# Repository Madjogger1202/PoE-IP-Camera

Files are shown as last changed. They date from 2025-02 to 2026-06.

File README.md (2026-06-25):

# PoE-IP-Camera

**IP-камера на ESP32-CAM с питанием от PoE (с гальванической развязкой), USB или DC-Jack и STM32-буфером между Ethernet и камерой.**

Плата сетевой камеры, где полезной нагрузкой выступает модуль **ESP32-CAM**, а связку с проводной сетью обеспечивает **Ethernet-контроллер**, подключённый к **STM32**, работающей буфером/мостом. Питание выбирается из трёх источников: **PoE**, **USB** или **DC-Jack (4.2–13 В)**. PoE-вход выполнен с гальванической развязкой. На ESP32-CAM реализуются веб-функции: Telegram-бот и API.

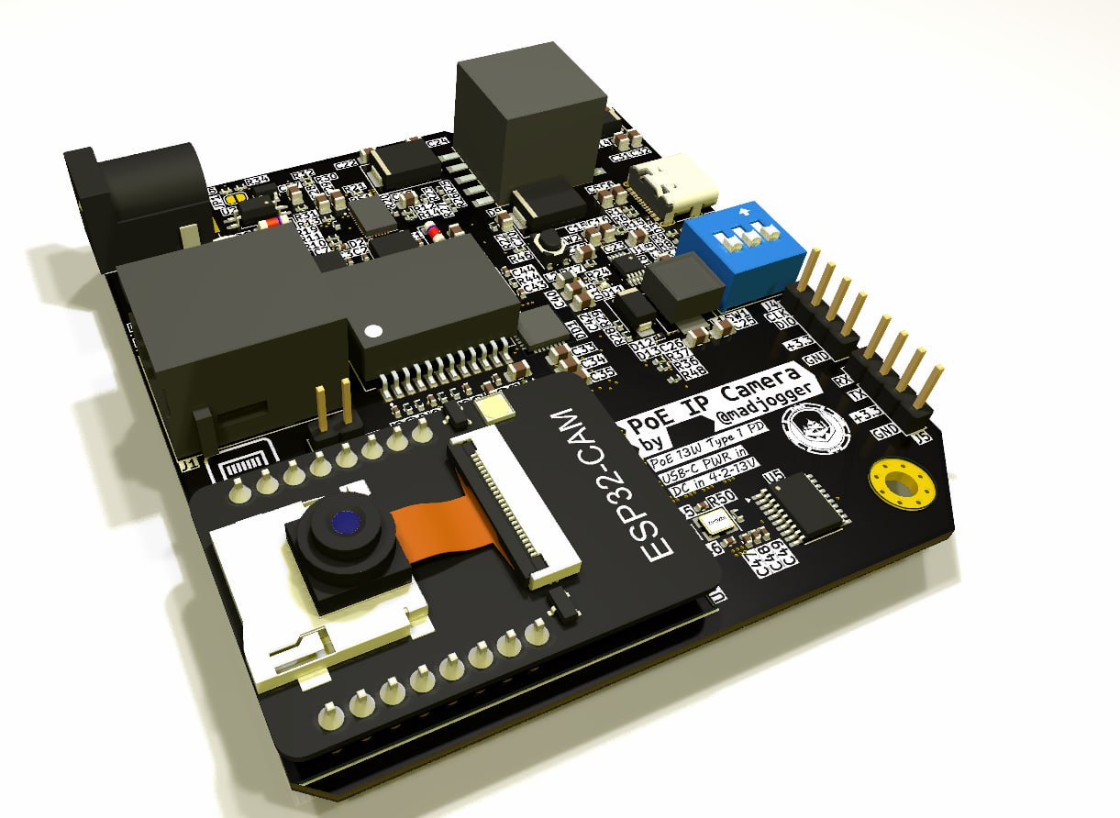
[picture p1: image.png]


## Обзор

- **Название проекта:** PoE-IP-Camera
- **Камера/нагрузка:** модуль ESP32-CAM (веб-сервер, Telegram-бот, API)
- **Сетевой узел:** Ethernet-контроллер + STM32 в роли буфера
- **Питание:** PoE (с развязкой) / USB / DC-Jack 4.2–13 В
- **Особенность:** изолированный PoE-вход — первый опыт проектирования гальванической развязки

## Ключевые особенности

- **Три источника питания** — PoE, USB или DC-Jack (4.2–13 В) на выбор
- **PoE с гальванической развязкой** — изолированный преобразователь питания на стороне PoE
- **ESP32-CAM как полезная нагрузка** — камера + Wi-Fi/обработка, веб-функции (Telegram-бот, API)
- **STM32-буфер** — промежуточное звено между Ethernet-контроллером и ESP32-CAM
- **Проводная сеть** — Ethernet-интерфейс для стабильного подключения и питания по одному кабелю (PoE)

## Архитектура

```
Сеть (Ethernet/PoE) ──► Ethernet-контроллер ──► STM32 (буфер) ──► ESP32-CAM (камера + веб)
                                                                       │
PoE / USB / DC-Jack ──► узел питания (PoE с развязкой) ────────────────┘
```

Сигнал из сети поступает на Ethernet-контроллер, который связан с STM32. STM32 работает буфером/мостом и передаёт данные на модуль ESP32-CAM — основную полезную нагрузку, на которой реализуются веб-интерфейс, Telegram-бот и API. Питание камера может получать по тому же кабелю (PoE) либо от USB/DC-Jack.

## Питание

Реализован выбор из трёх источников:

- **PoE** — питание по сетевому кабелю с **гальванической развязкой** (изолированный преобразователь)
- **USB** — питание от USB-разъёма
- **DC-Jack** — внешний вход **4.2–13 В**

Развязанный PoE-узел проектировался впервые и занял заметную часть работы; результат подтвердил корректность подхода.

## Что на плате

| Блок | Назначение |
|---|---|
| ESP32-CAM | Камера и веб-нагрузка (Telegram-бот, API) |
| Ethernet-контроллер | Проводной сетевой интерфейс |
| STM32 | Буфер/мост между Ethernet и ESP32-CAM |
| Узел питания PoE | Изолированный преобразователь (гальваническая развязка) |
| Выбор питания | Коммутация PoE / USB / DC-Jack (4.2–13 В) |

## Применение

- Сетевая IP-камера с питанием по одному кабелю (PoE)
- Удалённое наблюдение с управлением через Telegram-бот / API
- Узел видеомониторинга для систем с проводной сетью
- Платформа для экспериментов с PoE и связкой Ethernet ↔ ESP32-CAM

## Среда разработки

- **Схема и плата:** KiCad
- **Прошивка ESP32-CAM:** PlatformIO / Arduino (веб-сервер, Telegram-бот, API)
- **Прошивка STM32:** STM32Cube / PlatformIO

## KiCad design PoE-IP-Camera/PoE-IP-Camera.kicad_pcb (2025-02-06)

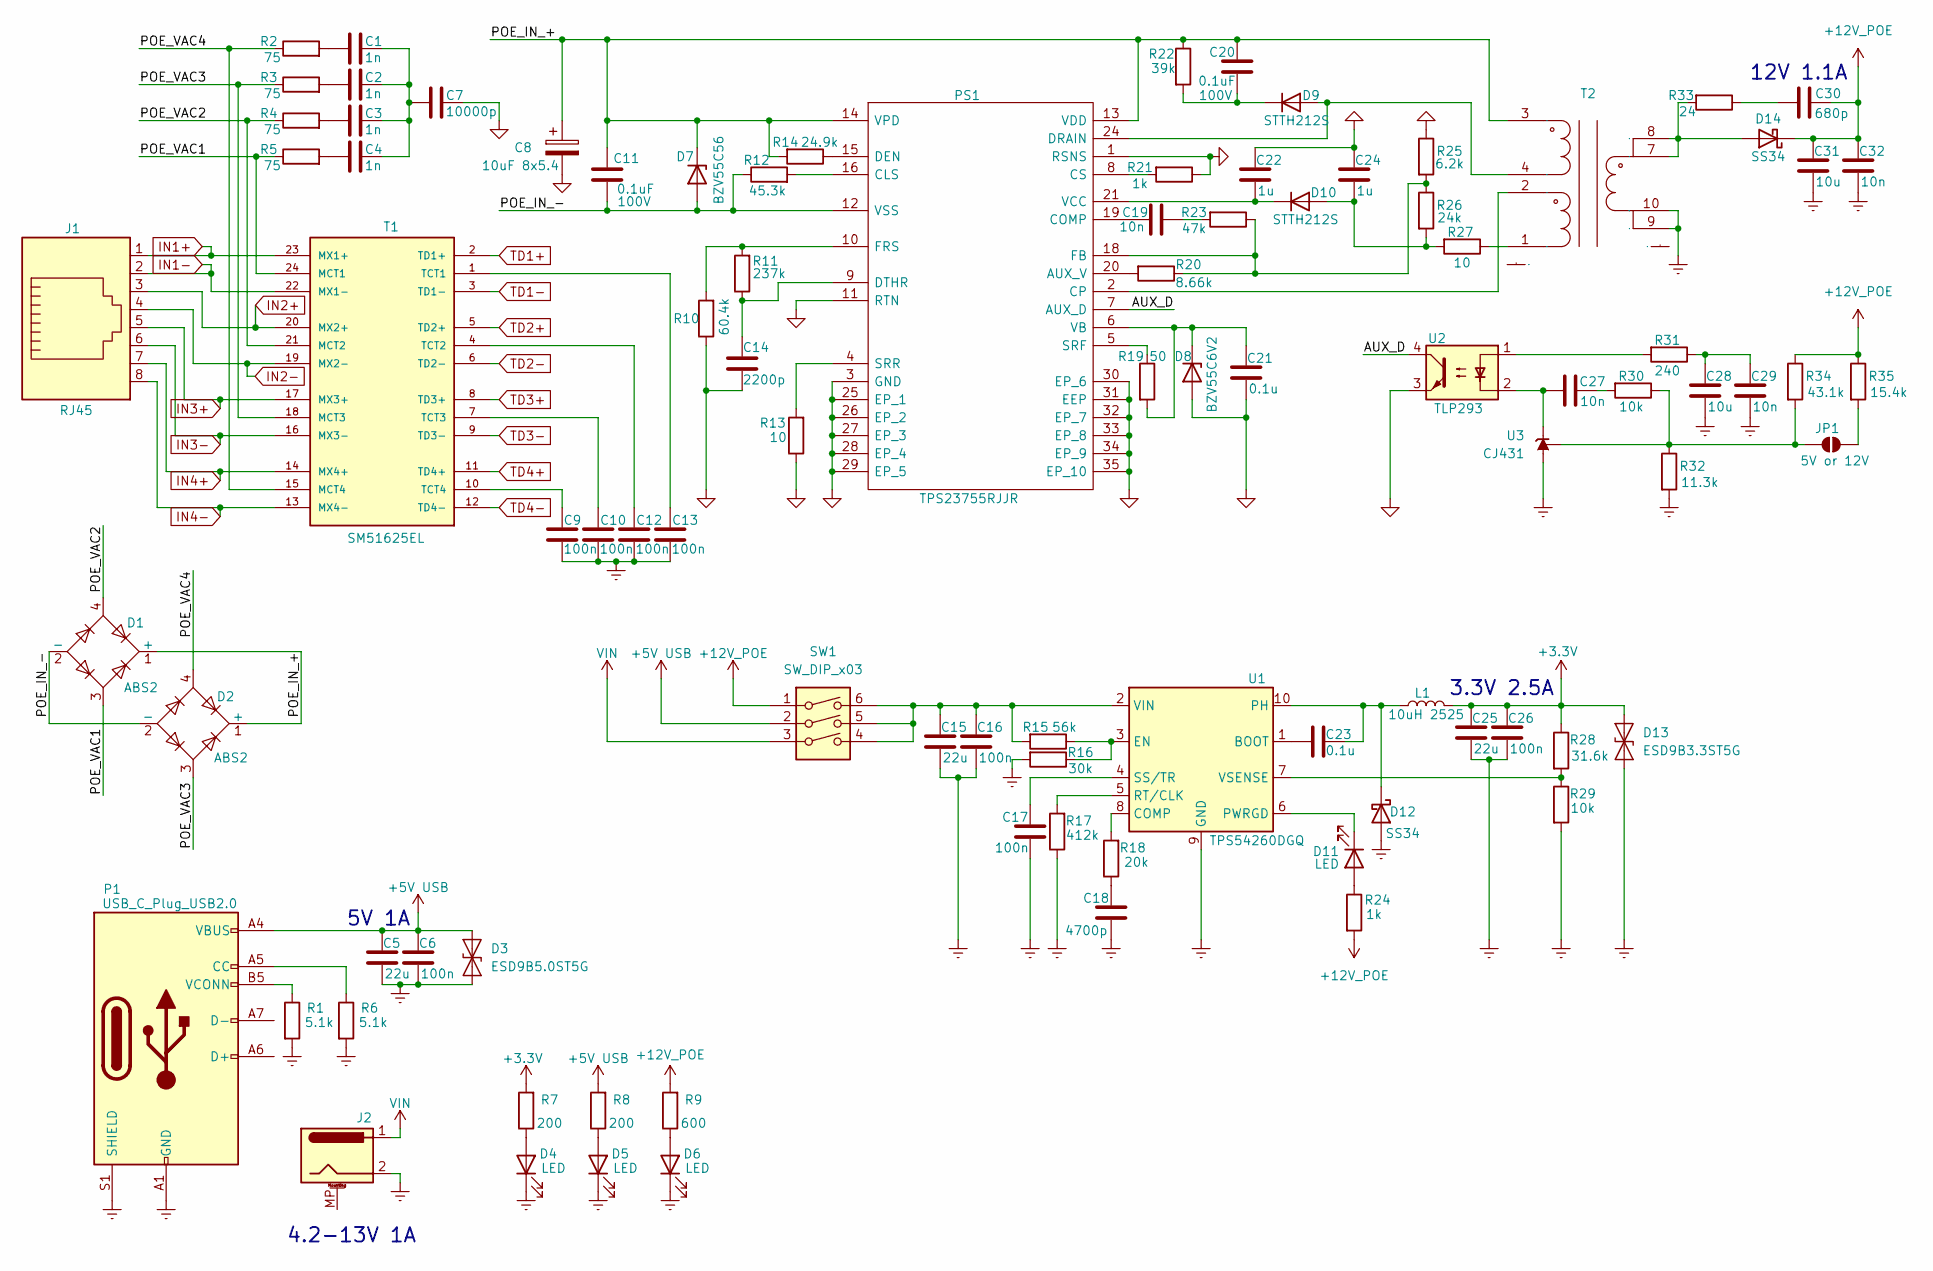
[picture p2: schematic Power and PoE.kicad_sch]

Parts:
C1, C2, C3, C4: 1n; C_0402_1005Metric
C5, C15, C25: 22u; C_0805_2012Metric
C6, C16, C17, C26: 100n; C_0805_2012Metric
C7: 10000p; C_0402_1005Metric
C8: 10uF 8x5.4; CP_Elec_8x5.4
C9, C10, C12, C13: 100n; C_0402_1005Metric
C11, C20: 0.1uF; C_0805_2012Metric
C14: 2200p; C_0805_2012Metric
C18: 4700p; C_0805_2012Metric
C19, C27, C29, C32: 10n; C_0805_2012Metric
C21, C23: 0.1u; C_0805_2012Metric
C22, C24: 1u; C_0805_2012Metric
C28, C31: 10u; C_0805_2012Metric
C30: 680p; C_0805_2012Metric
D1, D2: ABS2; Diode_Bridge_Diotec_ABS
D3: ESD9B5.0ST5G; D_SOD-923
D4, D5, D6, D11: LED; LED_0402_1005Metric
D7: BZV55C56; D_MiniMELF
D8: BZV55C6V2; D_MiniMELF
D9, D10: STTH212S; D_SMC
D12, D14: SS34; D_SMA
D13: ESD9B3.3ST5G; D_SOD-923
J1: RJ45; RJ45_Amphenol_54602-x08_Horizontal
J2: Barrel_Jack_MountingPin; BarrelJack_GCT_DCJ200-10-A_Horizontal
JP1: SolderJumper_2_Open; SolderJumper-2_P1.3mm_Open_RoundedPad1.0x1.5mm
L1: 10uH 2525; L_Vishay_IHLP-2525
P1: USB_C_Plug_USB2.0; USB_C_Receptacle_G-Switch_GT-USB-7010ASV
PS1: TPS23755RJJR
R1, R6: 5.1k; R_0402_1005Metric
R2, R3, R4, R5: 75; R_0402_1005Metric
R7, R8: 200; R_0402_1005Metric
R9: 600; R_0402_1005Metric
R10: 60.4k; R_0402_1005Metric
R11: 237k; R_0402_1005Metric
R12: 45.3k; R_0402_1005Metric
R13, R27: 10; R_0402_1005Metric
R14: 24.9k; R_0402_1005Metric
R15: 56k; R_0402_1005Metric
R16: 30k; R_0402_1005Metric
R17: 412k; R_0402_1005Metric
R18: 20k; R_0402_1005Metric
R19: 50; R_0402_1005Metric
R20: 8.66k; R_0402_1005Metric
R21, R24: 1k; R_0402_1005Metric
R22: 39k; R_0402_1005Metric
R23: 47k; R_0402_1005Metric
R25: 6.2k; R_0402_1005Metric
R26: 24k; R_0402_1005Metric
R28: 31.6k; R_0402_1005Metric
R29, R30: 10k; R_0402_1005Metric
R31: 240; R_0402_1005Metric
R32: 11.3k; R_0402_1005Metric
R33: 24; R_1206_3216Metric
R34: 43.1k; R_0402_1005Metric
R35: 15.4k; R_0402_1005Metric
SW1: SW_DIP_x03; SW_DIP_SPSTx03_Slide_9.78x9.8mm_W7.62mm_P2.54mm
T1: SM51625EL; XFMR_SM51625EL
T2: XFMR-SMD_HR051142; Manufacturer Part HR051142
U1: TPS54260DGQ; MSOP-10-1EP_3x3mm_P0.5mm_EP2.2x3.1mm_Mask1.83x1.89mm_Therma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
U2: TLP293; SOIC-4_4.55x2.6mm_P1.27mm
U3: CJ431; SOT-23

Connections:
+3.3V: C25.1, C26.1, D13.2 (A2), L1.2, R7.2, R28.1; also elsewhere on the board
+5V USB: C5.1, C6.1, D3.2 (A2), P1.A4 (VBUS), P1.A9 (VBUS), P1.B4 (VBUS), P1.B9 (VBUS), R8.2, SW1.2
+12V_POE: C30.2, C31.1, C32.1, D14.1 (K), R9.2, R24.2, R34.1, R35.1, SW1.1
/Power and PoE/AUX_D: PS1.7 (AUX_D), U2.4
/Power and PoE/POE_IN_+: C8.1, C11.1, C20.1, D1.1 (+), D2.1 (+), D7.1 (K), PS1.13 (VDD), PS1.14 (VPD), R14.2, R22.1, T2.3
/Power and PoE/POE_IN_-: C11.2, D1.2 (-), D2.2 (-), D7.2 (A), PS1.12 (VSS), R12.1
/Power and PoE/POE_VAC1: D1.3, R5.1, T1.24 (MCT1)
/Power and PoE/POE_VAC2: D1.4, R4.1, T1.21 (MCT2)
/Power and PoE/POE_VAC3: D2.3, R3.1, T1.18 (MCT3)
/Power and PoE/POE_VAC4: D2.4, R2.1, T1.15 (MCT4)
Earth: C5.2, C6.2, C9.1, C10.1, C12.1, C13.1, C15.2, C16.2, C17.2, C18.2, C25.2, C26.2, C28.2, C29.2, C31.2, C32.2, D3.1 (A1), D4.1 (K), D5.1 (K), D6.1 (K), D12.2 (A), D13.1 (A1), J2.2, P1.A1 (GND), P1.A12 (GND), P1.B1 (GND), P1.B12 (GND), P1.S1 (SHIELD), R1.2, R6.2, R16.2, R17.1, R29.2, R32.2, T2.9, T2.10, U1.9 (GND), U1.11, U3.3 (A); also elsewhere on the board
GND1: C7.1, C8.2, C14.2, C21.2, C22.1, C24.1, D8.2 (A), PS1.1 (RSNS), PS1.3 (GND), PS1.11 (RTN), PS1.25 (EP_1), PS1.26 (EP_2), PS1.27 (EP_3), PS1.28 (EP_4), PS1.29 (EP_5), PS1.30 (EP_6), PS1.31 (EEP), PS1.32 (EP_7), PS1.33 (EP_8), PS1.34 (EP_9), PS1.35 (EP_10), R10.1, R13.1, R21.1, R25.1, U2.3
IN1+: J1.1, T1.23 (MX1+)
IN1-: J1.2, T1.22 (MX1-)
IN2+: J1.3, T1.20 (MX2+)
IN2-: J1.4, T1.19 (MX2-)
IN3+: J1.5, T1.17 (MX3+)
IN3-: J1.6, T1.16 (MX3-)
IN4+: J1.7, T1.14 (MX4+)
IN4-: J1.8, T1.13 (MX4-)
unnamed: C1.1, C2.1, C3.1, C4.1, C7.2
unnamed: C1.2, R2.2
unnamed: C2.2, R3.2
unnamed: C3.2, R4.2
unnamed: C4.2, R5.2
unnamed: C18.1, R18.1
unnamed: C19.2, R23.2
unnamed: C27.2, R30.2
unnamed: C28.1, C29.1, R31.1
unnamed: C30.1, R33.1
unnamed: D4.2 (A), R7.1
unnamed: D5.2 (A), R8.1
unnamed: D6.2 (A), R9.1
unnamed: C21.1, D8.1 (K), PS1.6 (VB), R19.2
unnamed: D9.2 (A), PS1.24 (DRAIN), T2.4
unnamed: C20.2, D9.1 (K), R22.2
unnamed: C24.2, D10.2 (A), R26.2, R27.2
unnamed: C22.2, D10.1 (K), PS1.21 (VCC)
unnamed: D11.2 (A), R24.1
unnamed: D11.1 (K), U1.6 (PWRGD)
unnamed: C23.2, D12.1 (K), L1.1, U1.10 (PH)
unnamed: D14.2 (A), R33.2, T2.7, T2.8
unnamed: JP1.1 (A), R30.1, R32.1, R34.2, U3.1 (REF)
unnamed: JP1.2 (B), R35.2
unnamed: P1.A5 (CC), R6.1
unnamed: P1.B5 (VCONN), R1.1
unnamed: PS1.20 (AUX_V), R20.2
unnamed: PS1.16 (CLS), R12.2
unnamed: C19.1, PS1.19 (COMP)
unnamed: PS1.2 (CP), T2.2
unnamed: PS1.8 (CS), R21.2
unnamed: PS1.15 (DEN), R14.1
unnamed: C14.1, PS1.9 (DTHR), R11.1
unnamed: PS1.18 (FB), R20.1, R23.1, R25.2, R26.1
unnamed: PS1.10 (FRS), R10.2, R11.2
unnamed: PS1.5 (SRF), R19.1
unnamed: PS1.4 (SRR), R13.2
unnamed: R27.1, T2.1
unnamed: R31.2, U2.1
unnamed: C13.2, T1.1 (TCT1)
unnamed: C12.2, T1.4 (TCT2)
unnamed: C10.2, T1.7 (TCT3)
unnamed: C9.2, T1.10 (TCT4)
unnamed: C23.1, U1.1 (BOOT)
unnamed: R18.2, U1.8 (COMP)
unnamed: R15.1, R16.1, U1.3 (EN)
unnamed: R17.2, U1.5 (RT/CLK)
unnamed: C17.1, U1.4 (SS/TR)
unnamed: C15.1, C16.1, R15.2, SW1.4, SW1.5, SW1.6, U1.2 (VIN)
unnamed: R28.2, R29.1, U1.7 (VSENSE)
unnamed: C27.1, U2.2, U3.2 (K)
TD1+: T1.2 (TD1+); also elsewhere on the board
TD1-: T1.3 (TD1-); also elsewhere on the board
TD2+: T1.5 (TD2+); also elsewhere on the board
TD2-: T1.6 (TD2-); also elsewhere on the board
TD3+: T1.8 (TD3+)
TD3-: T1.9 (TD3-)
TD4+: T1.11 (TD4+)
TD4-: T1.12 (TD4-)
VIN: J2.1, SW1.3

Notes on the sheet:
3.3V 2.5A
12V 1.1A
5V 1A
4.2-13V 1A

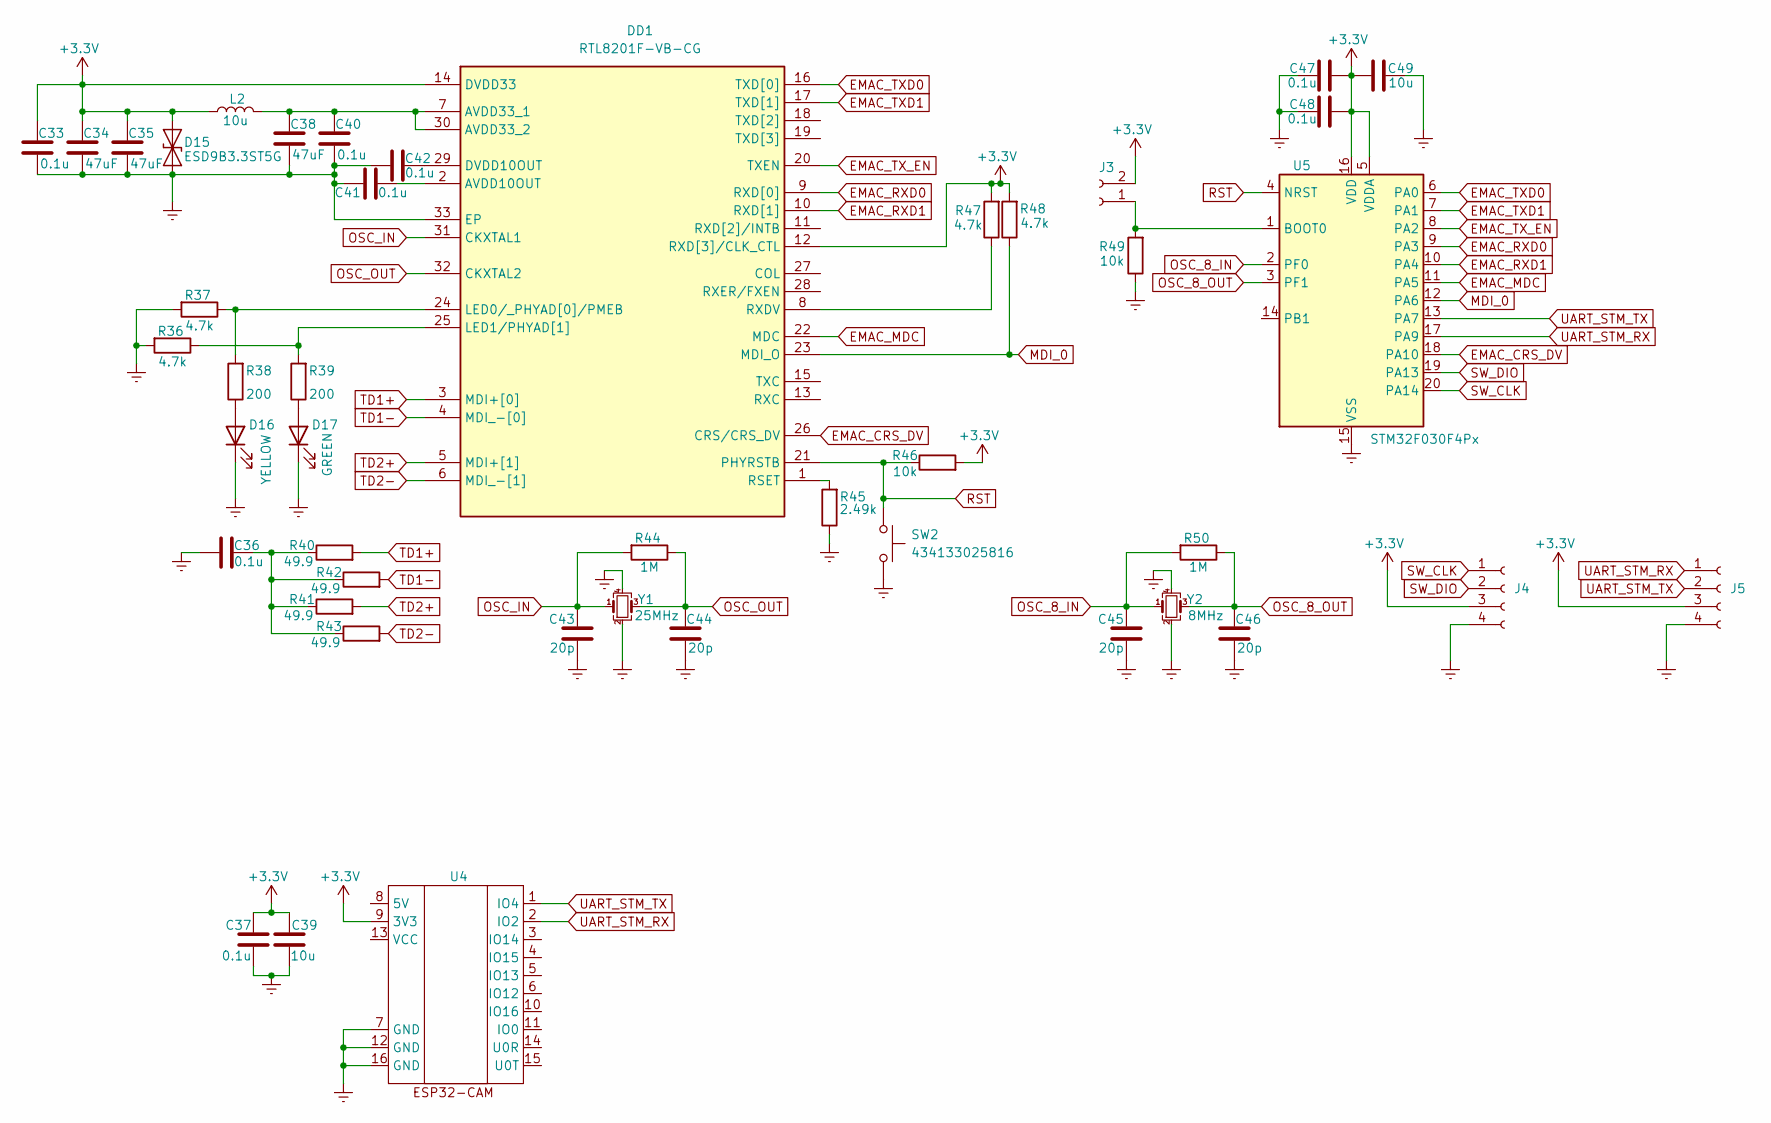
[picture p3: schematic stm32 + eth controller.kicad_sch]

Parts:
C33, C40, C41, C42: 0.1u; C_0805_2012Metric
C34, C35, C38: 47uF; C_0805_2012Metric
C36: 0.1u; C_0603_1608Metric
C37, C47, C48: 0.1u; C_0402_1005Metric
C39, C49: 10u; C_0402_1005Metric
C43, C44, C45, C46: 20p; C_0402_1005Metric
D15: ESD9B3.3ST5G; D_SOD-923
D16: YELLOW; LED_0402_1005Metric
D17: GREEN; LED_0402_1005Metric
DD1: RTL8201F-VB-CG; QFN50P500X500X100-33N; Manufacturer_Part_Number RTL8201F-VB-CG
J3: Conn_01x0; PinHeader_1x02_P2.54mm_Vertical
J4, J5: Conn_01x04_Socket; PinHeader_1x04_P2.54mm_Vertical
L2: 10u; L_0805_2012Metric
R36, R37, R47, R48: 4.7k; R_0402_1005Metric
R38, R39: 200; R_0402_1005Metric
R40, R41, R42, R43: 49.9; R_0402_1005Metric
R44, R50: 1M; R_0402_1005Metric
R45: 2.49k; R_0402_1005Metric
R46, R49: 10k; R_0402_1005Metric
SW2: 434133025816; SW_Push_1P1T_NO_Vertical_Wuerth_434133025816
U4: COMM-TH_16P-L40.0-W27.0-P2.54_ESP32-CAM
U5: STM32F030F4Px; TSSOP-20_4.4x6.5mm_P0.65mm
Y1, Y2: X322525MOB4SI; Oscillator_SMD_Abracon_ASE-4Pin_3.2x2.5mm

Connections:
+3.3V: C33.1, C34.1, C35.1, C37.1, C39.2, C47.1, C48.1, C49.1, D15.2 (A2), DD1.12 (RXD[3]/CLK_CTL), DD1.14 (DVDD33), J3.2, J4.3, J5.3, L2.1, R46.2, R47.2, R48.2, U4.9 (3V3), U5.5 (VDDA), U5.16 (VDD); also elsewhere on the board
EMAC_CRS_DV: DD1.26 (CRS/CRS_DV), U5.18 (PA10)
EMAC_MDC: DD1.22 (MDC), U5.11 (PA5)
EMAC_RXD0: DD1.9 (RXD[0]), U5.9 (PA3)
EMAC_RXD1: DD1.10 (RXD[1]), U5.10 (PA4)
EMAC_TXD0: DD1.16 (TXD[0]), U5.6 (PA0)
EMAC_TXD1: DD1.17 (TXD[1]), U5.7 (PA1)
EMAC_TX_EN: DD1.20 (TXEN), U5.8 (PA2)
Earth: C33.2, C34.2, C35.2, C36.1, C37.2, C38.2, C39.1, C40.2, C41.1, C42.1, C43.1, C44.2, C45.1, C46.2, C47.2, C48.2, C49.2, D15.1 (A1), D16.1 (K), D17.1 (K), DD1.33 (EP), J4.4, J5.4, R36.2, R37.2, R45.1, R49.1, SW2.2, U4.7 (GND), U4.12 (GND), U4.16 (GND), U5.15 (VSS), Y1.2, Y1.4, Y2.2, Y2.4; also elsewhere on the board
MDI_0: DD1.23 (MDI_O), R48.1, U5.12 (PA6)
unnamed: C36.2, R40.1, R41.1, R42.1, R43.1
unnamed: D16.2 (A), R38.1
unnamed: D17.2 (A), R39.1
unnamed: C41.2, DD1.2 (AVDD10OUT)
unnamed: C38.1, C40.1, DD1.7 (AVDD33_1), DD1.30 (AVDD33_2), L2.2
unnamed: C42.2, DD1.29 (DVDD10OUT)
unnamed: DD1.24 (LED0/_PHYAD[0]/PMEB), R37.1, R38.2
unnamed: DD1.25 (LED1/PHYAD[1]), R36.1, R39.2
unnamed: DD1.1 (RSET), R45.2
unnamed: DD1.8 (RXDV), R47.1
unnamed: J3.1, R49.2, U5.1 (BOOT0)
OSC_8_IN: C45.2, R50.2, U5.2 (PF0), Y2.1
OSC_8_OUT: C46.1, R50.1, U5.3 (PF1), Y2.3
OSC_IN: C43.2, DD1.31 (CKXTAL1), R44.2, Y1.1
OSC_OUT: C44.1, DD1.32 (CKXTAL2), R44.1, Y1.3
RST: DD1.21 (PHYRSTB), R46.1, SW2.1, U5.4 (NRST)
SW_CLK: J4.1, U5.20 (PA14)
SW_DIO: J4.2, U5.19 (PA13)
TD1+: DD1.3 (MDI+[0]), R40.2; also elsewhere on the board
TD1-: DD1.4 (MDI_-[0]), R42.2; also elsewhere on the board
TD2+: DD1.5 (MDI+[1]), R41.2; also elsewhere on the board
TD2-: DD1.6 (MDI_-[1]), R43.2; also elsewhere on the board
UART_STM_RX: J5.1, U4.2 (IO2), U5.17 (PA9)
UART_STM_TX: J5.2, U4.1 (IO4), U5.13 (PA7)

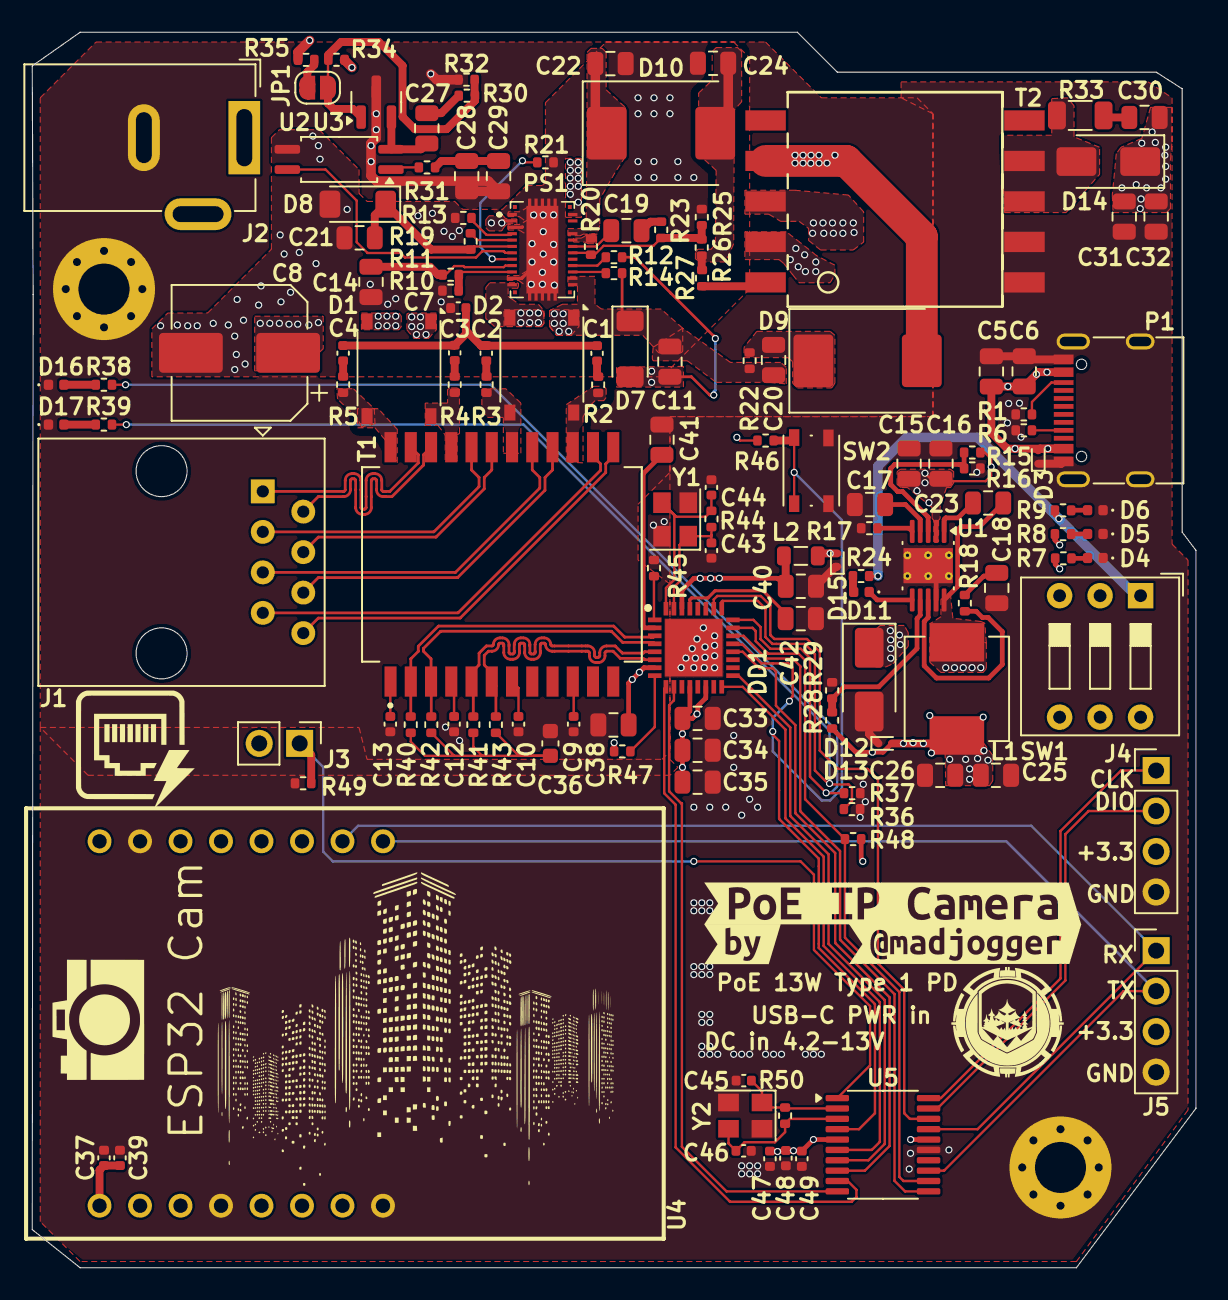
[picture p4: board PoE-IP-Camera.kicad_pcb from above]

Board: 4 copper layers, 73.0 x 77.5 mm, 141 parts (0 on the bottom side), 104 nets.

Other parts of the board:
kibuzzard-67A49B3B: G***; kibuzzard-67A49B3B
kibuzzard-67A49B47: G***; kibuzzard-67A49B47
kibuzzard-67A498E6: G***; kibuzzard-67A498E6

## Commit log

2025-02-03 rev0 without routing
    [PoE-IP-Camera.kicad_pcb, PoE-IP-Camera.kicad_sch, Power and PoE.kicad_sch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]
2025-02-03 частичная трассировка
    [PoE-IP-Camera.kicad_pcb, Power and PoE.kicad_sch, stm32 + eth controller.kicad_sch]
2025-02-05 чут чут трассировки
    [PoE-IP-Camera.kicad_pcb, Power and PoE.kicad_sch, stm32 + eth controller.kicad_sch]
2025-02-06 Завершение трассировки
    [PoE-IP-Camera.kicad_pcb]
